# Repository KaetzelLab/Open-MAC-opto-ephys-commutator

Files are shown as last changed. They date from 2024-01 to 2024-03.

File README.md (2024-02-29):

# Open-MAC opto-ephys-commutator
#### For Ephys, miniscope and Ephys+ miniscope commutator please visit below link
https://github.com/KaetzelLab/Open-MAC.git

BOM is updated, and we kindly request the users to refer BOM from GitHub to build the new version of the commutator

#### All in one (two optic fiber and SPI cable for Ephys)

<p align="Left">    
    
</p>

#### Single optic fiber and SPI cable for Ephys

<p align="Left">    
    
</p>

# Citation
If you find this repository and documents useful cite us as 

Sampath K.T. Kapanaiah, Dennis Kätzel, (2023). Open-MAC: A low-cost open-source motorized commutator for electro- and opto-physiological recordings in freely moving rodents, HardwareX, Volume 14,2023,e00429, ISSN 2468-0672,https://doi.org/10.1016/j.ohx.2023.e00429.

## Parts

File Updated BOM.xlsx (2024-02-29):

Designator | Component | Number | Cost per unit (EUR) | Total cost (EUR) | Manufacturer Number | Source of material | Material type
Top PCB | Top PCB | 1 | 1.00 | 1.00 | na | JLC PCB or PCB way | printed circuit board
Bottom PCB | Bottom PCB | 1 | 1.00 | 1.00 | na | JLC PCB or PCB way | printed circuit board
Bottom PCB | Hall Sensor | 2 | 0.30 | 0.60 | na | https://www.amazon.de/gp/product/B07ZDJSZSG/ref=ppx_yo_dt_b_asin_title_o04_s00?ie=UTF8&psc=1 | IC
Top PCB, Bottom PCB | slide switch | 2 | 0.42 | 0.84 | 1825232-1 | https://www.mouser.de/ProductDetail/TE-Connectivity-PB/1825232-1?qs=kTKVN3NWb5FosGxaNC1%252BtA%3D%3D | Plastic, Metal
Top PCB | Linear voltage drop out regulator (LDO) | 1 | 0.61 | 0.61 | MC7805BDTRKG | https://www.mouser.de/ProductDetail/onsemi/MC7805BDTRKG?qs=%252B9%2Fcbd0IE0RVSCV5SBH6%2FA%3D%3D | IC
Top PCB | Capacitors | 2 | 0.15 | 0.30 | 581-08055A101MAT2A | https://eu.mouser.com/ProductDetail/KYOCERA-AVX/08055A101MAT2A?qs=zdK0ZDdZmgzjgZCLHBg27Q%3D%3D | ceramic capacitor
Top PCB | Microcontroller (XIAO or XIAO ESP32C3) | 1 | 4.99 | 4.99 | XIAO ESP32C3 | https://www.seeedstudio.com/Seeed-XIAO-ESP32C3-p-5431.html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 | IC
Top PCB | DC Power jack barrel | 1 | 1.02 | 1.02 | 694106301002 | https://www.mouser.de/ProductDetail/Wurth-Elektronik/694106301002?qs=a9WhcLg8qCwOEkcI62k5mA%3D%3D | Plastic, Metal
Top PCB | Jumper | 1 | 0.70 | 0.70 | - | https://www.amazon.de/-/en/Black-Standard-Short-Circuit-Jumper/dp/B00R1LEP6G | Plastic, Metal
Top PCB | Stepper driver | 1 | 10.00 | 10.00 | TMC2208 or TMC2209 | https://www.amazon.de/-/en/dp/B0893DPSJL/ref=twister_B09V7H96P6?th=1 | IC, PCB
Top PCB | Connector 7P and 8P | 4 | 2.99 | 11.99 | - | https://www.amazon.de/-/en/Female-Straight-Connector-Arduino-Prototype/dp/B093LBN495?s=ce-de | plastic, metal
Top PCB, Bottom PCB | Resistors | 2 | 0.44 | 0.88 | MBA02040C1002FC100 | https://www.mouser.de/ProductDetail/Vishay-Beyschlag/MBA02040C1002FC100?qs=nlQjf3QnJCoHnMMMaOw%2FFA%3D%3D | metal film resistor
Top PCB, Bottom PCB | 2P Terminal Block Connector | 25 | 0.30 | 7.50 | - | https://www.amazon.de/gp/product/B08HWP26RB/ref=ppx_yo_dt_b_asin_image_o00_s00?ie=UTF8&psc=1 | plastic, metal
Center case A | Stepper motor | 1 | 22.00 | 22.00 | NEMA-7 | https://www.amazon.de/gp/product/B07SPK6BT4/ref=ppx_yo_dt_b_asin_title_o07_s00?ie=UTF8&psc=1 | metal, semiconductor
Magnet holder | Magnet (cylinder 3x4mm)** | 2 | 0.16 | 0.32 | - | https://www.kjmagnetics.com/proddetail.asp?prod=D22 | Neodynium
Center case A | Ball Bearing (7x42x30) | 1 | 2.60 | 2.60 | 6806-2RS | https://www.amazon.de/-/en/sourcing-6806-2RS-Groove-Bearing-Double/dp/B082PYHLC2?s=industrial | steel
Bottm case B | Ball Bearing ( 3 x 10 x 4 mm) | 1 | 0.90 | 0.90 | 623-2RS | https://www.amazon.de/gp/product/B07CWLGNJ5/ref=ppx_yo_dt_b_asin_title_o06_s00?ie=UTF8&psc=1 | steel
- | M2.5x5.7mm threaded inserts | 30 | 0.12 | 3.60 | - | https://www.amazon.de/dp/B088QJDPKK?psc=1&ref=ppx_yo2ov_dt_b_product_details | steel
- | M2.5x35mm Screws | 10 | 0.24 | 2.40 | - | https://www.amazon.de/-/en/US-SA-AJD-99450/dp/B012TE3VJG | steel
- | M2.5x8mm Screws | 20 | 0.18 | 3.60 | - | https://www.amazon.de/-/en/sourcingmap-Button-Hexagon-Socket-Screw/dp/B01D4VH1YO | steel
- | M3x4mm threaded inserts | 4 | 0.09 | 0.36 | - | https://www.amazon.de/-/en/ruthex-Threaded-Insert-RX-M3x5-7-Ultrasonic/dp/B08BCRZZS3 | brass
- | M3x6mm screws | 3 | 0.07 | 0.21 | - | https://www.amazon.de/-/en/countersunk-screws-hexagon-socket-pieces/dp/B07YZGR7ZC | steel
- | M3x50mm screws | 1 | 0.17 | 0.17 | - | https://www.amazon.de/-/en/countersunk-screws-hexagon-socket-pieces/dp/B07YZM98J3 | steel
3D printed parts | 3D printed parts | 1 | - | 60.00 | - | -
Sum total of costs for any commutator type |  |  |  | 137.59
Parts that are ordered in dependence on the specific commutator type to be built
Top PCB, Bottom PCB | SMA Connector (Miniscope)* | 0 / 2 | 7.13 | 14.26 | 73251-2209 | https://www.mouser.de/ProductDetail/Molex/73251-2209?qs=vxeUf0TWHS1jQq9gJekxHg%3D%3D | gold-plated metal
Top PCB, Bottom PCB | Omnetics Horizontal SMT PZN-12-AA* | 0 / 2 / 4 | 42.39 | 84.78 | A79623-001 | https://www.omnetics.com/products/neuro-connectors/nano-strip-polarized | composite
slip-ring | slip-ring for 12-channel SPI* | 0 / 1 | 20.00 | 20.00 | M220A-18 / M125-18 | https://www.senring.com/capsule-slip-ring/m220.html | plastic, conductive material
slip-ring | slip-ring for 24-channel SPI* | 0 / 1 | 75.00 | 75.00 | M220A-36 | https://www.senring.com/capsule-slip-ring/m220.html | plastic, conductive material
slip-ring | slip-ring for high-speed RF-line* | 0 / 1 | 85.00 | 85.00 | O022-12 / O022-08 | https://www.senring.com/hd-sdi-1080p-slip-ring/o022-12.html | plastic, conductive material
slip-ring | slip-ringfor 12-channel SPI & RF-line* | 0 / 1 | 145.00 | 145.00 | O032-24 | https://www.senring.com/hd-sdi-1080p-slip-ring/o032-24.html | plastic, conductive material
slip-ring | slip-ring for 12-channel SPI & through-hole* | 0 / 1 | 130.00 | 130.00 | H1532-24S | https://www.senring.com/through-hole-slip-ring/small-hole/h1532.html | plastic, conductive material
Sum total of costs for specific commutator type
Electrophysiology 12-channel SPI (32 recording channels) |  |  |  | 242.37
Electrophysiology 24-channel SPI (64 recording channels) |  |  |  | 382.15
Miniscope only |  |  |  | 236.85
Electrophysiology 12-channel SPI (32 recording channels) and Miniscope |  |  |  | 381.63
Electrophysiology 12-channel SPI (32 recording channels) and Optogenetics |  |  |  | 352.38
* Distinct numbers are stated for these items because their usage depends on the type of commutator that is built. At the bottom of the table, all 5 types that can be built with the unmodified design files provided here and on https://zenodo.org/record/7253652 are listed and their costs are stated.
** Alternative source at a price of 0.30 €/unit: https://www.amazon.de/-/en/10-Mini-Neodymium-Magnets-Ultra-Strong-Original/dp/B01JEK4A4I

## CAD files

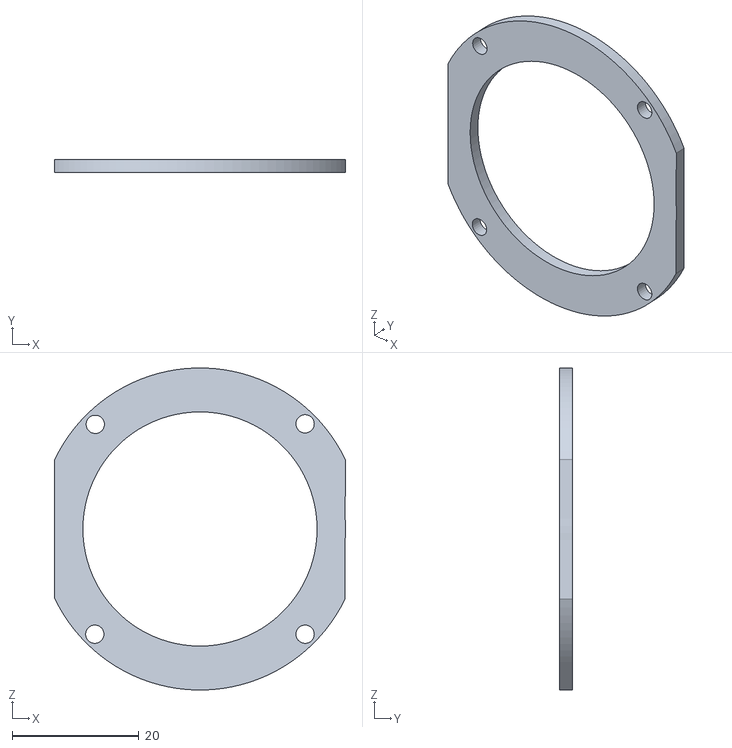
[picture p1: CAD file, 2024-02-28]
Open-MAC stl design files/Com_Center_Bearing_Assembly_B.stl.stl
46.0 x 2.00 x 50.9

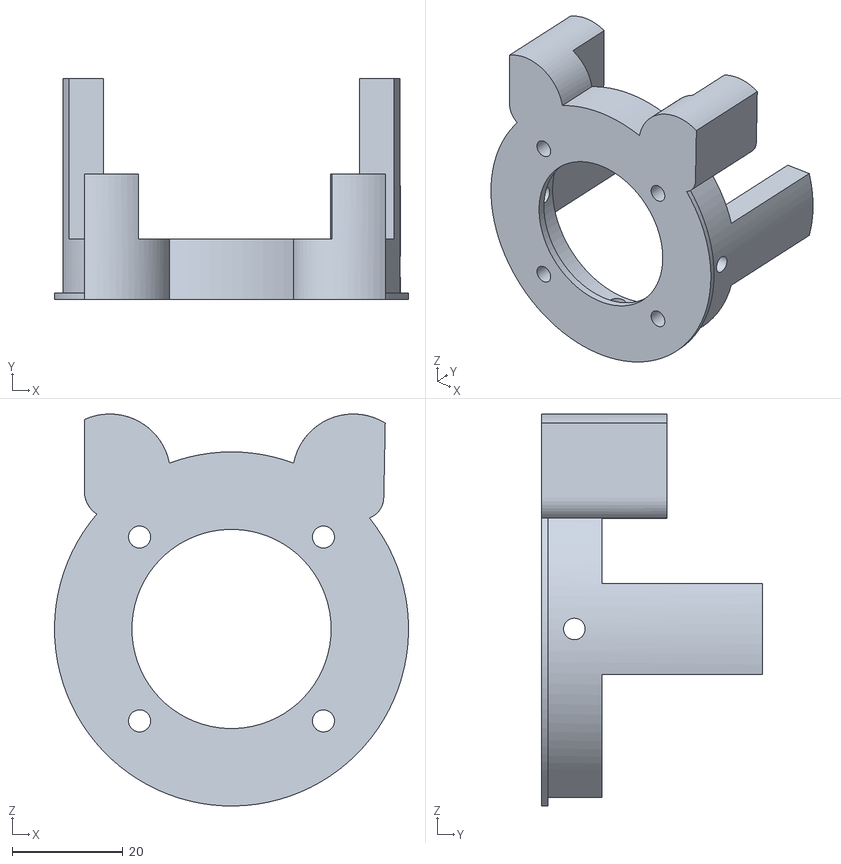
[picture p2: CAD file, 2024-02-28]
Open-MAC stl design files/Com_Center_Bearing_Assembly_A.stl.stl
64.0 x 40.0 x 70.8

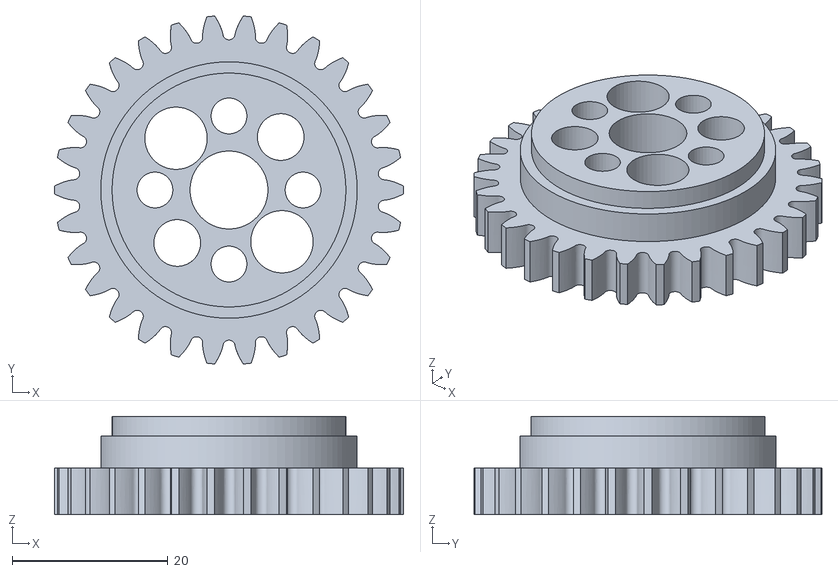
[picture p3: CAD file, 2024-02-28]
Open-MAC stl design files/Com_Main_Spur_Gear.stl
44.8 x 44.6 x 12.6

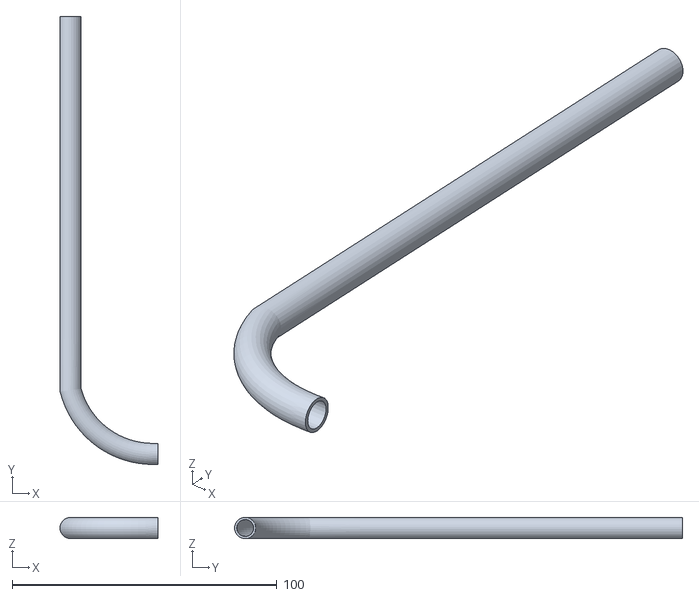
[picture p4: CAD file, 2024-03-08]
Open-MAC stl design files/Tubing.stl
37.0 x 169.1 x 8.00

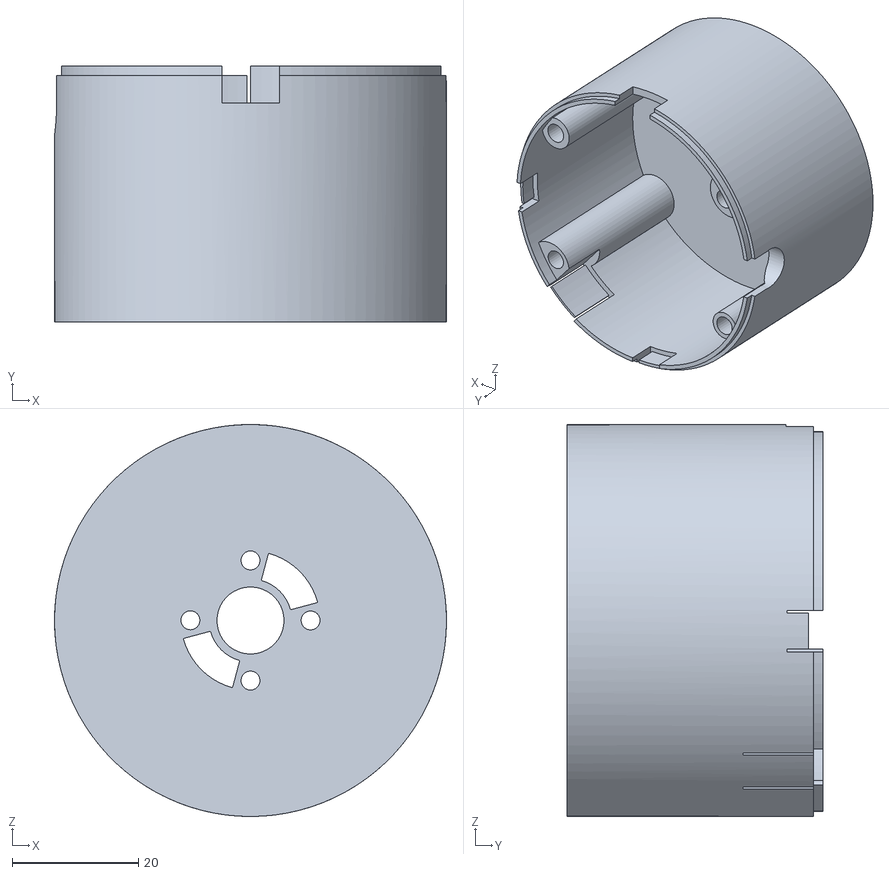
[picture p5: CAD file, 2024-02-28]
Open-MAC stl design files/Com_Bottom_A.stl
62.0 x 40.5 x 62.0

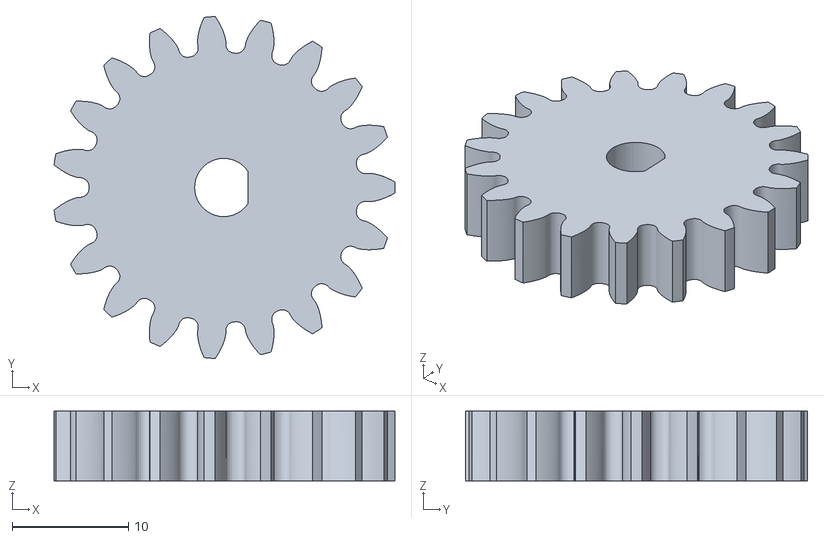
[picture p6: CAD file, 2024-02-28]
Open-MAC stl design files/Com_secondary_Spur_Gear.stl
29.3 x 29.4 x 6.00

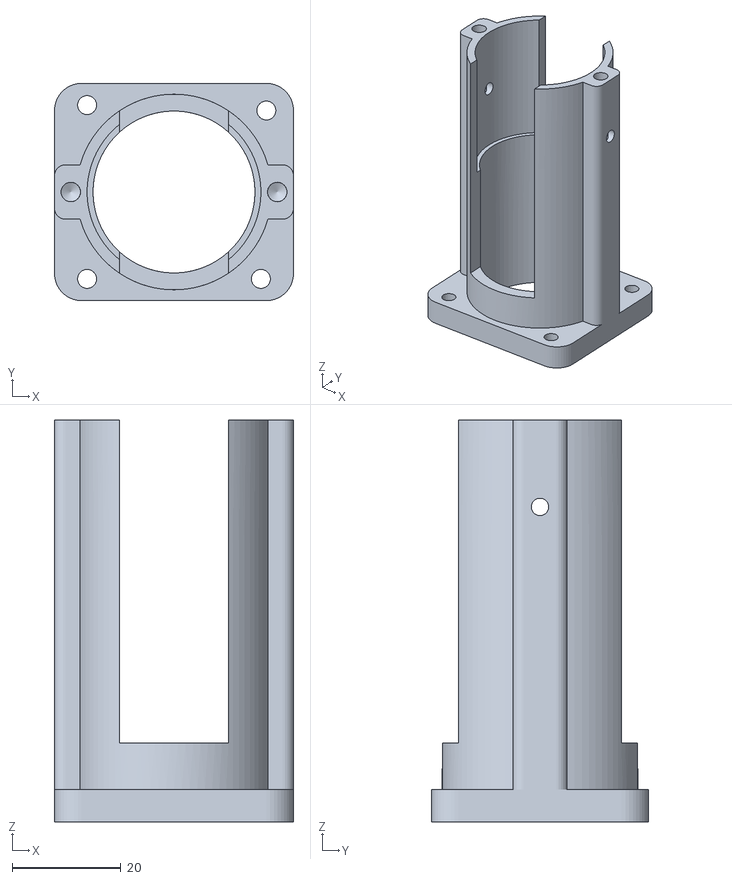
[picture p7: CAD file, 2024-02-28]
Open-MAC stl design files/OptoAdapter_A.stl
44.0 x 40.0 x 74.0

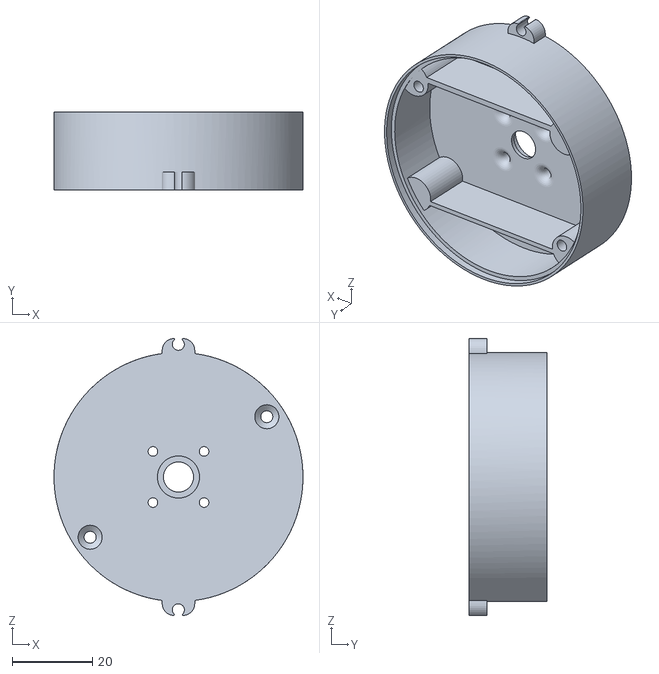
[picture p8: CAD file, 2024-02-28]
Open-MAC stl design files/Com_Bottom_B.stl
62.0 x 19.4 x 69.0

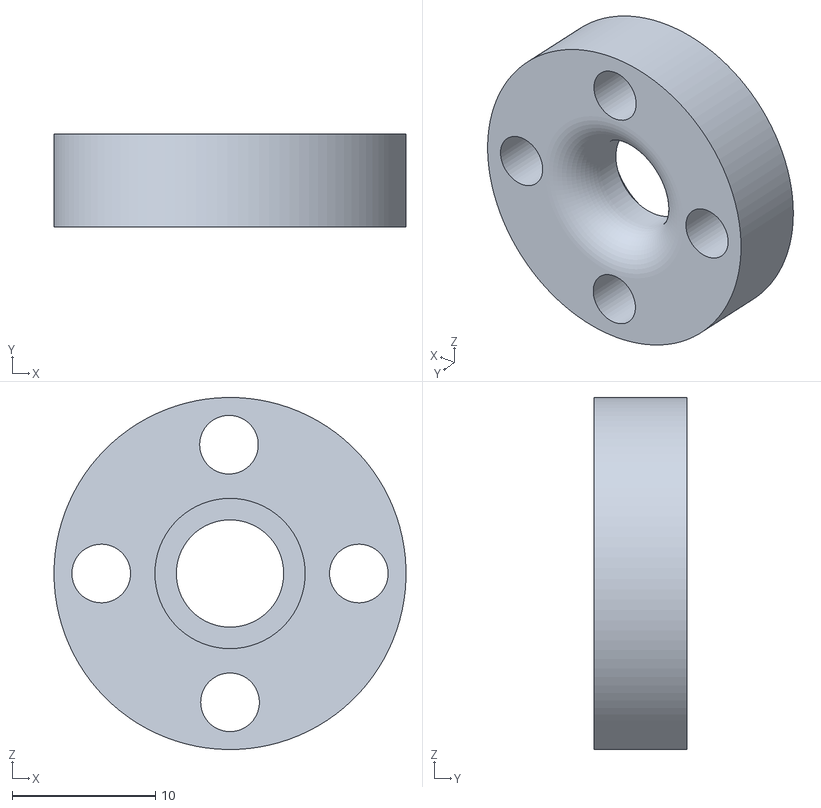
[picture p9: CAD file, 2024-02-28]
Open-MAC stl design files/Com_Bottom_C.stl
24.6 x 6.50 x 24.6

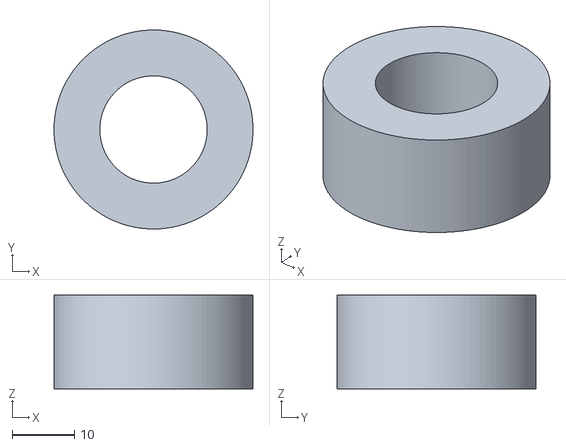
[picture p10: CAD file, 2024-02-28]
Open-MAC stl design files/Opto_Inner for single fiber.stl
31.9 x 31.9 x 15.0

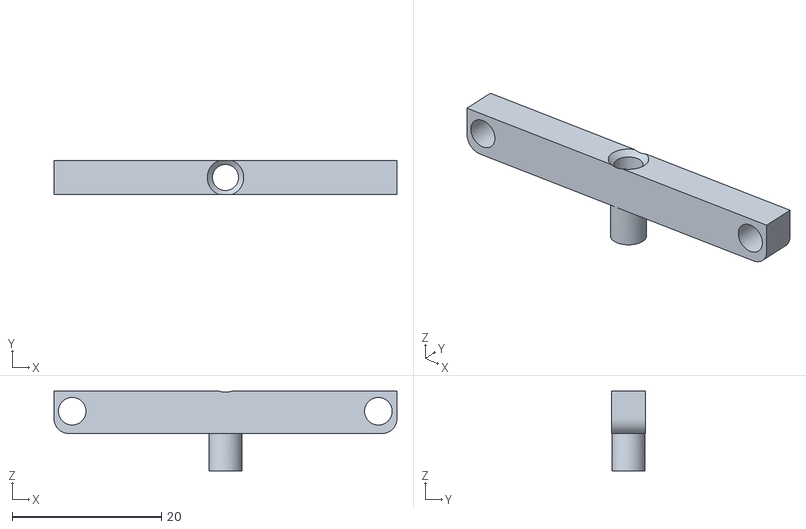
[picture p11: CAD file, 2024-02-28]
Open-MAC stl design files/Com_MagnetMount.stl
46.0 x 4.60 x 10.7

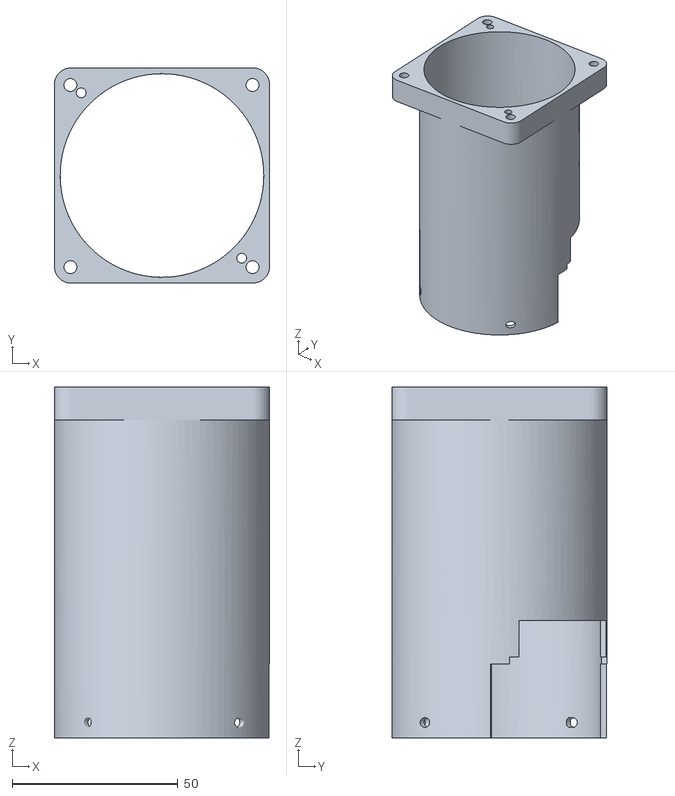
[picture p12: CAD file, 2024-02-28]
Open-MAC stl design files/Com_Top_B_Final.stl
65.1 x 65.1 x 106.0

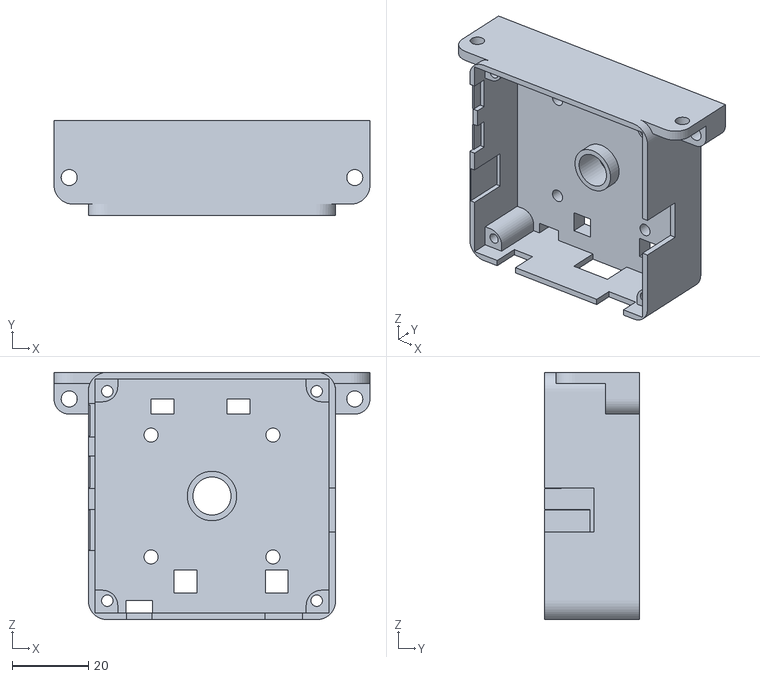
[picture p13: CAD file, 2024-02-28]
Open-MAC stl design files/Com_Top_A.stl
83.0 x 25.0 x 65.0

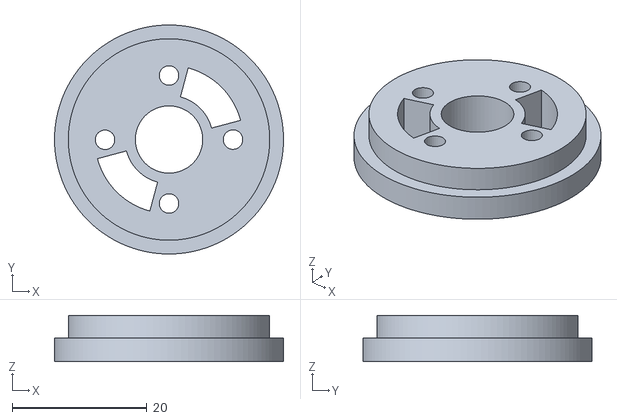
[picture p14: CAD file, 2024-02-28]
Open-MAC stl design files/Com_Center_Beraing_Inner_Adapter.stl
34.0 x 34.0 x 6.90

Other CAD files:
Open-MAC stl design files/CableAdapter.stl
Open-MAC stl design files/Commutator holder.stl

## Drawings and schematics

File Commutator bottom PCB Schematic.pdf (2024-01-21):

SCLK- | T2 OE1
SCLK- | T2 OE2

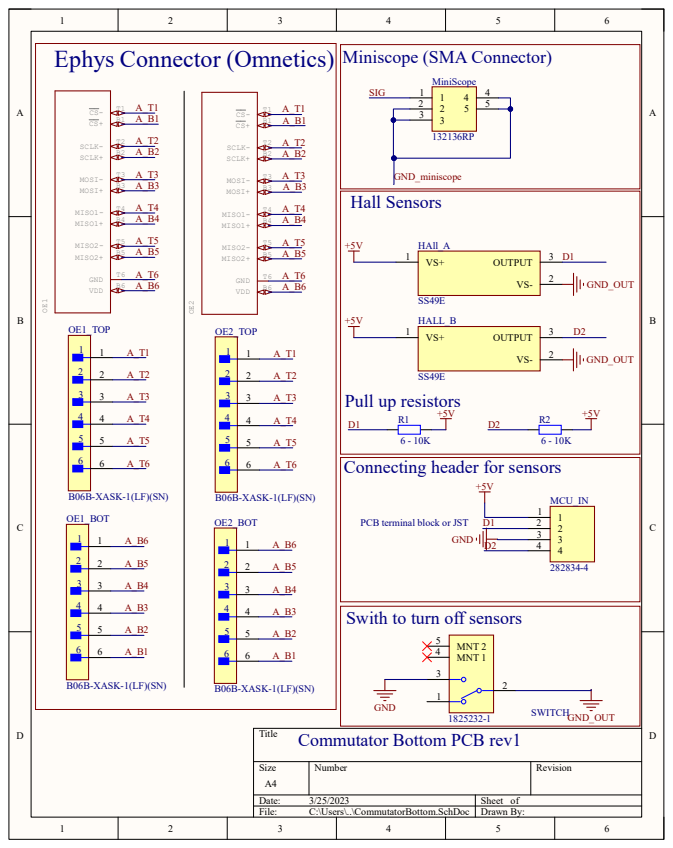
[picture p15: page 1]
Size; Number; Revision; Date:; Sheet of; File:; C:\Users\..\CommutatorBottom.SchDoc; Drawn By:; OE1_TOP; OE1_BOT; MISO2-; MISO1+; MISO2+; VDD; GND; MOSI-; SCLK+; MISO1-; MOSI+; OE2_TOP; OE2_BOT; MiniScope; GND_miniscope; SIG; OUTPUT; HAll_A; HALL_B; GND_OUT; Hall Sensors; MNT 1 4; MNT 2 5; SWITCH 1825232-1; MCU_IN

Ephys Connector (Omnetics) Miniscope (SMA Connector)

Pull up resistors

Connecting header for sensors

B06B-XASK-1(LF)(SN)

PCB terminal block or JST

Swith to turn off sensors

Title
Commutator Bottom PCB rev1

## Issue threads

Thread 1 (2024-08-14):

the top PCB

ChangQing-SH, 2024-08-14:
Hi,

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

What are the two parts used near the TMC2209? which can't be found on the schematic.
and the BOM lists 0805 capacitors, which seems small to fit the top PCB footprint,

Best,
Jon

KaetzelLab, 2024-08-14:
Hi Jon,

These are male header pins to adjust stepper resolution (MS1 and MS2). You don't need any particular components for this; you can short-circuit them to change the resolution. By default, it is 8 micro steps (both pulled up to GND), so these pins give you the option to set it to VCC (pul High).

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

Best,
Dennis

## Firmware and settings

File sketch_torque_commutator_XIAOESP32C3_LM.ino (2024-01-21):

//this is sketch file for torque mode operation of Open-MAC commutator
int dirPin = D7;   // Direction was 7
int stepPin = D8;  // Step
int EnPin = D9;    // Enable was 9

int sensorReading_delay = 0;
int step_delay_dur = 500;
int stepsPerRevolution = 50;

void setup() {
  Serial.begin(9600);
  // initial speed and the target position
  pinMode(EnPin, OUTPUT);
  pinMode(dirPin, OUTPUT);
  pinMode(stepPin, OUTPUT);
  // Hall sensors
  pinMode(A1, INPUT);
  pinMode(A2, INPUT);
  digitalWrite(EnPin, HIGH);
}

void loop() {
  if (digitalRead(A2) == 0) {
    digitalWrite(dirPin, HIGH);
    digitalWrite(EnPin, LOW);
    for (int i = 0; i < stepsPerRevolution; i++) {
      digitalWrite(stepPin, HIGH);
      delayMicroseconds(step_delay_dur);
      digitalWrite(stepPin, LOW);
      delayMicroseconds(step_delay_dur);
    }
    digitalWrite(EnPin, HIGH);
  } else if (digitalRead(A1) == 0) {
    digitalWrite(dirPin, LOW);
    digitalWrite(EnPin, LOW);
    for (int i = 0; i < stepsPerRevolution; i++) {
      digitalWrite(stepPin, HIGH);
      delayMicroseconds(step_delay_dur);
      digitalWrite(stepPin, LOW);
      delayMicroseconds(step_delay_dur);
    }
    digitalWrite(EnPin, HIGH);
  }
}
